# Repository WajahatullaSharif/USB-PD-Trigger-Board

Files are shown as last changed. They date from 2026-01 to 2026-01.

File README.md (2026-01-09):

# **USB C PD Trigger Board**
- The USB PD Trigger Board is based on **AP33771C USB PD3.1 ERP sink controller** from Diodes Incorporated. 
- This board negotiates required **voltages (5V/9V/12V/15V/20V/28V) and current (0 to 5A max)** profiles requested using the respective jumpers with the Type C Power Source (typically charger/adaptor). 
- It includes safety features like Over/Under Voltage, Over Current, Over Temperature Protections along with IN/OUT isolation. The board is also immune to ± 30 kV Air/Contact ESD dicharge (IEC 61000-4-2)

# Kicad 9 files
- The hardware is designed on KiCad 9.
## Schematic
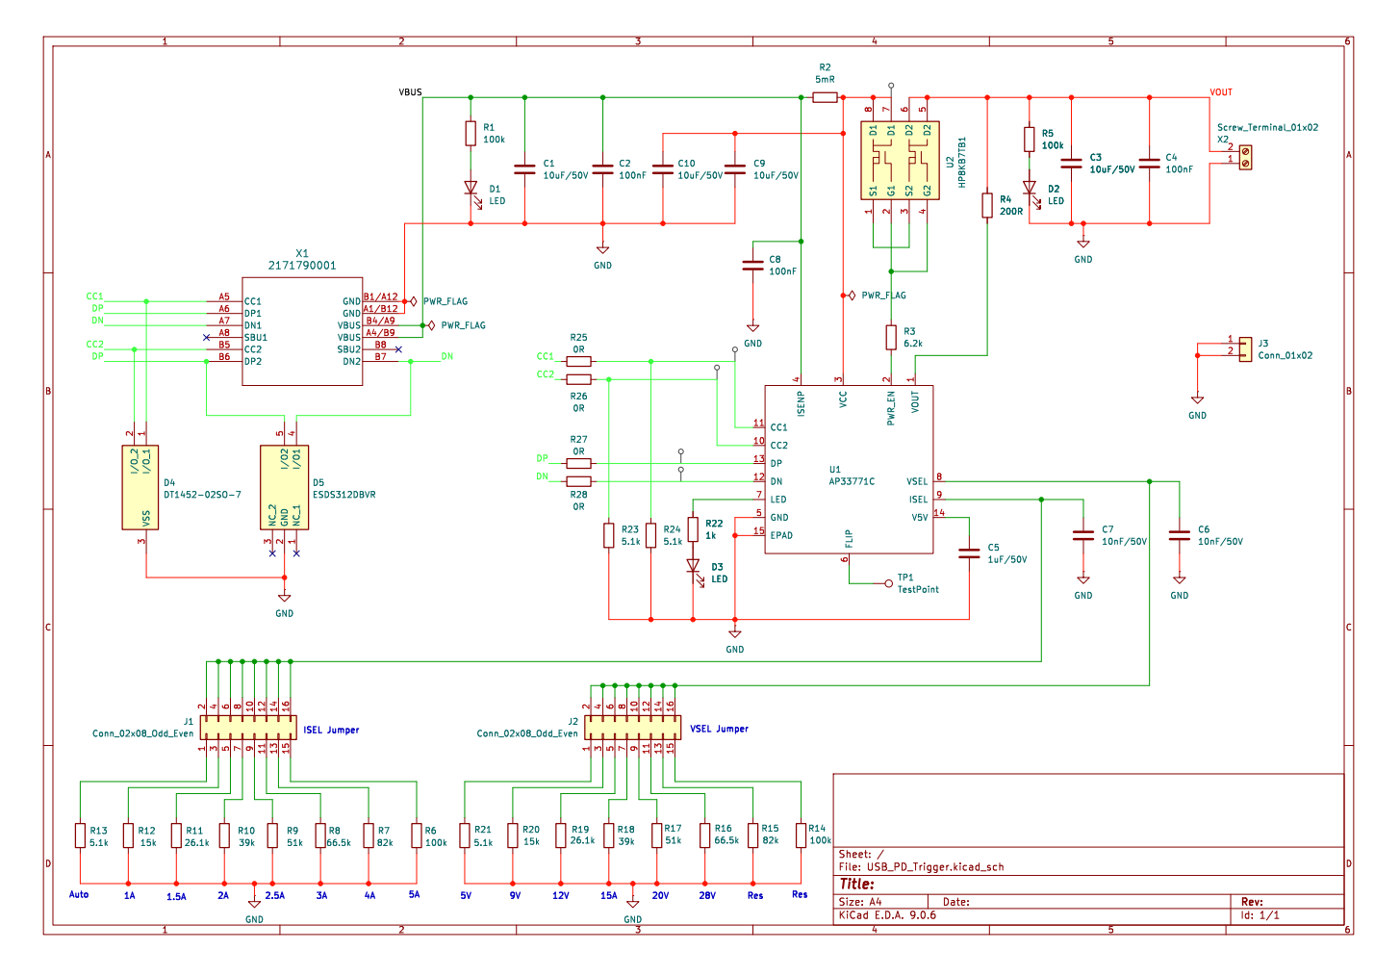
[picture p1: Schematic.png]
Schematic

## Layout
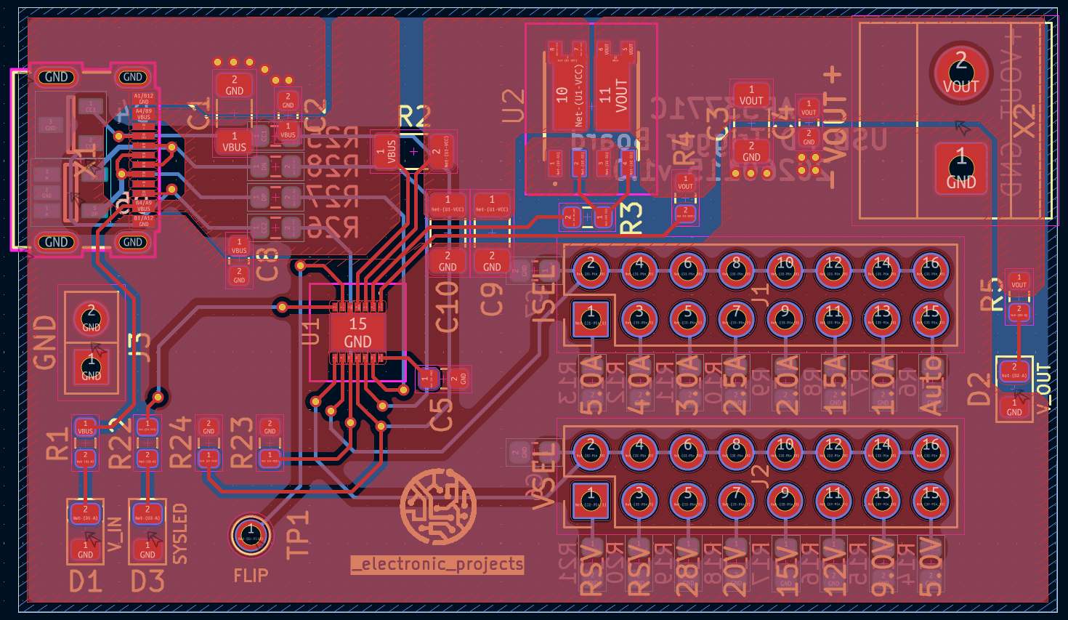
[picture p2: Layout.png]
Layout

## 3D Model
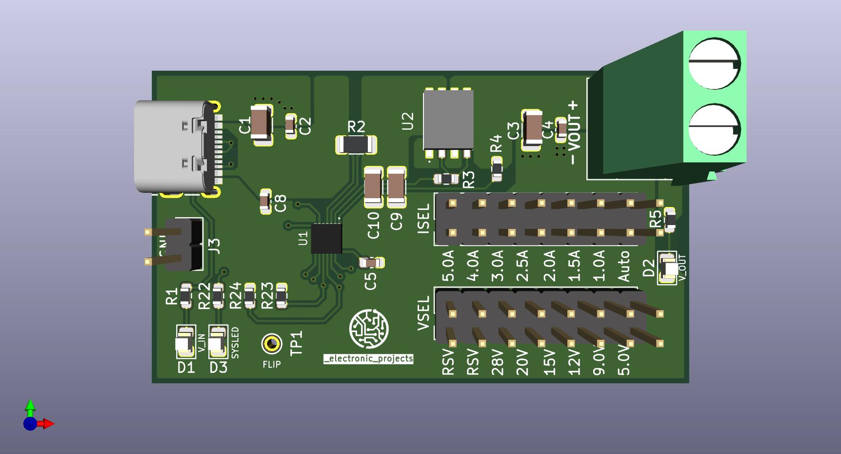
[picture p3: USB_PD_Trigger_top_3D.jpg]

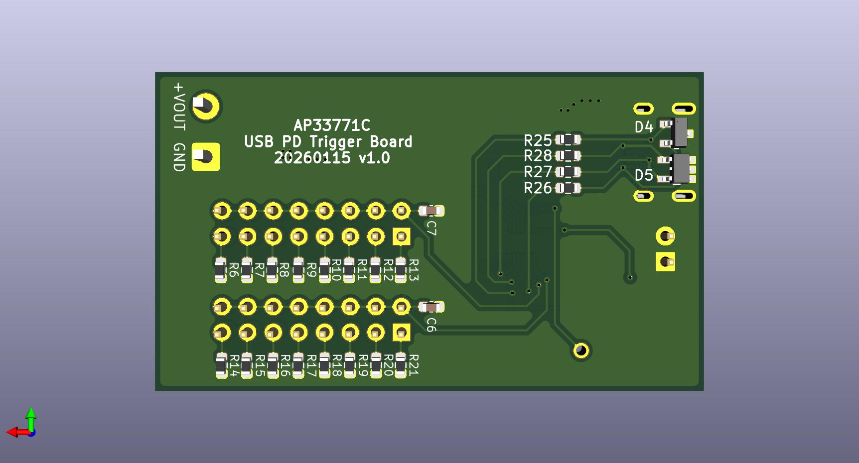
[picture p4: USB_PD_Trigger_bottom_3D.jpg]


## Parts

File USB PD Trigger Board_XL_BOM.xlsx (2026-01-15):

Sr.No | Ref Des | Qty | Value | MPN | Make | Alternates/Substitutes | Make | Total Cost
1 | C1, C3, C9, C10 | 4 | CER 10UF 50V X7R 1206 | CL31B106KBHNNNE | Samsung Electro-Mechanics |  |  | ₹167.00
2 | C2, C4, C8 | 3 | CER 100nF ±10% 50V X7R 0603 | GRM188R71H104KA93D | Murata |  |  | ₹92.00
3 | C5 | 1 | CER 1uF ±10% 50V X7R 0603 | CC0603KRX7R9BB105 | YAGEO |  |  | ₹163.00
4 | C6, C7 | 2 | CER 10nF ±10% 50V X7R 0603 | CC0603KRX7R9BB103 | YAGEO |  |  | ₹25.00
5 | D1 | 1 | 0805 GREEN SMD LED | APT2012CGCK | Kingbright |  |  | ₹149.00
6 | D2 | 1 | 0805 BLUE SMD LED | APT2012LVBC/D | Kingbright |  |  | ₹282.00
7 | D3 | 1 | 0805 ORANGE SMD LED | APT2012SECK/J4-PRV | Kingbright |  |  | ₹271.00
8 | D4 | 1 | TVS DIODE 5.5VWM 11VC SOT233 | DT1452-02SO-7 | Diodes Incorporated |  |  | ₹223.00
9 | D5 | 1 | TVS DIODE 3.6VWM 6.5VC SOT23-5 | ESDS312DBVR | Texas Instruments |  |  | ₹321.00
10 | U1 | 1 | USB EXT POWER RANGE W-DFN3030-14 | AP33771CFBZ-13-FA01 | Diodes Incorporated |  |  | ₹834.00
11 | U2 | 1 | 40V 24A, Dual Nch+Nch, HSOP8 | HP8KB7TB1 | ROHM Semiconductor |  |  | ₹1850.00
12 | R1, R5, R6, R14 | 4 | RES 100K OHM 1% 1/10W 0603 | RC0603FR-07100KL | YAGEO |  |  | ₹14.00
13 | R2 | 1 | RES 5m OHM 1% 1/2W 1206 | PA1206FRF7W0R005L | YAGEO |  |  | ₹300.00
14 | R3 | 1 | RES 6.2K OHM 5% 1/10W 0603 | RC0603JR-076K2L | YAGEO |  |  | ₹79.00
15 | R4 | 1 | RES 200Ohms 1/10W 0603 5 % | AF0603JR-07200RL | YAGEO |  |  | ₹79.00
16 | R7, R15 | 2 | RES 82K OHM 1% 1/10W 0603 | RC0603FR-0782KL | YAGEO |  |  | ₹15.00
17 | R8, R16 | 2 | RES 66.5K OHM 1% 1/10W 0603 | RC0603FR-0766K5L | YAGEO |  |  | ₹15.00
18 | R9, R17 | 2 | RES 52.3K OHM 1% 1/10W 0603 | RC0603FR-0752K3L | YAGEO |  |  | ₹27.00
19 | R10, R18 | 2 | RES 39K OHM 1% 1/10W 0603 | RC0603FR-0739KL | YAGEO |  |  | ₹15.00
20 | R11, R19 | 2 | RES 26.1K OHM 1% 1/10W 0603 | RC0603FR-0726K1L | YAGEO |  |  | ₹17.00
21 | R12, R20 | 2 | RES 15K OHM 1% 1/10W 0603 | RC0603FR-0715KL | YAGEO |  |  | ₹17.00
22 | R13, R21, R23, R24 | 4 | RES 5.1K OHM 1% 1/10W 0603 | RC0603FR-075K1L | YAGEO |  |  | ₹26.00
23 | R22 | 1 | RES 1K OHM 5% 1/10W 0603 | RC0603JR-071KL | YAGEO |  |  | ₹61.00
24 | R25, R26, R27, R28 | 4 | RES 0 OHM JUMPER 1/10W 0603 | RC0603JR-070RL | YAGEO |  |  | ₹26.00
25 | J1, J2 | 2 | Pin Header 16 Position 2.54mm Pitch Dual Row Through Hole -40℃~+105℃ | PZ254V-12-16P | XFCN | 5-146254-4 | TE Connectivity
26 | J3 | 1 | CONN HEADER VERT 2POS 2.54MM | TSW-102-07-F-S | Samtec Inc.
27 | X1 | 1 | CONN RCP USB2.0 TYP C 24P SMD RA | 2171790001 | Molex |  |  | ₹520.00
28 | X2 | 1 | 2 Position Wire to Board Terminal Block Through Hole 5mm | KF301-5.0-2P | Cixi Kefa Elec | TB002-500-02BE | Same Sky
 |  |  |  |  |  | TSW-108-07-F-D | Samtec Inc.
 |  |  |  |  |  | 691137710002 | Würth Elektronik
 |  |  |  |  |  |  | Shipping cost | ₹250.00
 |  |  |  |  |  |  | Total cost | ₹5838.00

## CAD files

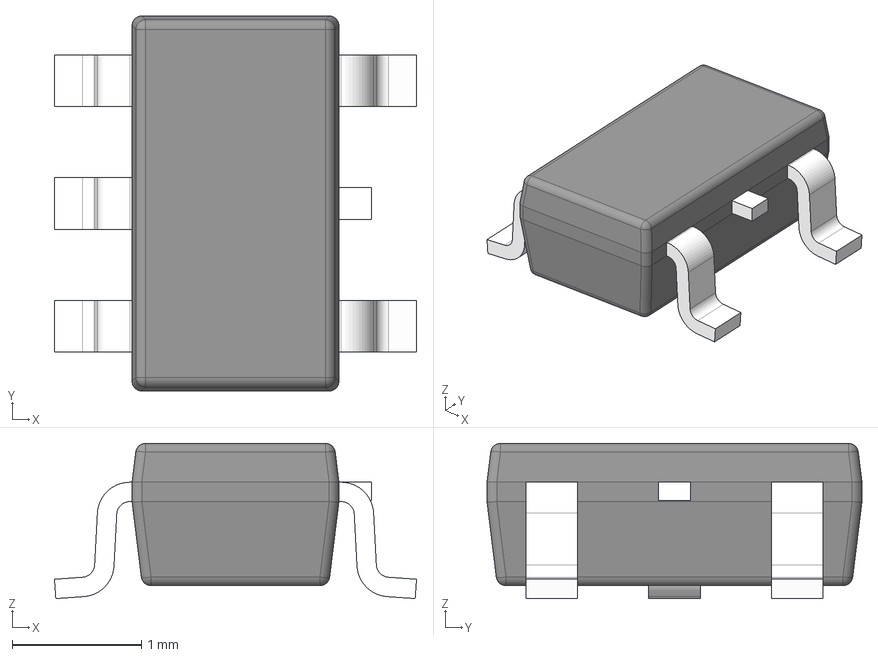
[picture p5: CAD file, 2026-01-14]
3dmodels/ESDS312DBVR.stp
2.80 x 2.90 x 1.20 mm
BODY-SOT
LEAD-SOT x 5
LEAD-DUMMY

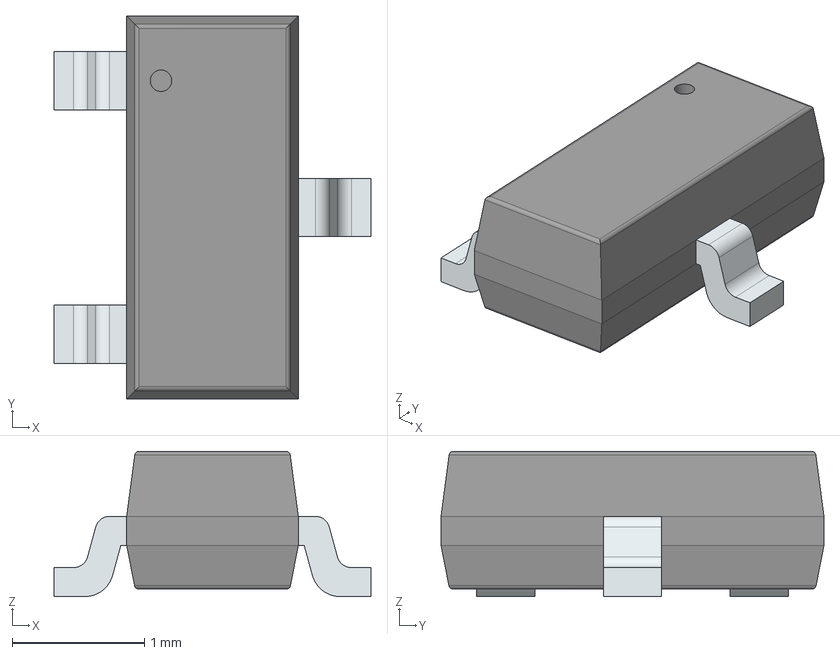
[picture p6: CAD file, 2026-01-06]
3dmodels/DT1452-02SO-7.stp
2.40 x 2.90 x 1.10 mm
PinsArrayL
FilletPinR

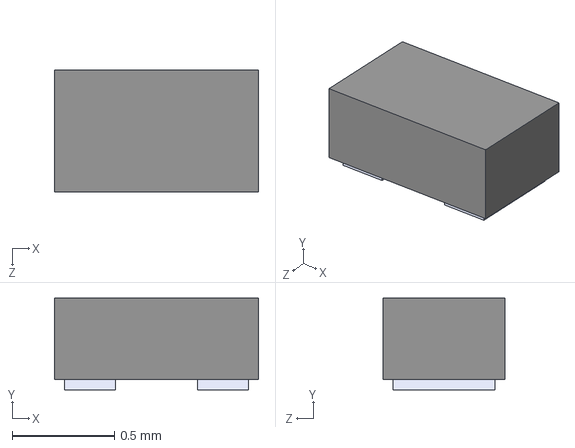
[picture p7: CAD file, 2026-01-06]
3dmodels/ESD321DPYR.STEP
1.00 x 0.45 x 0.6 mm

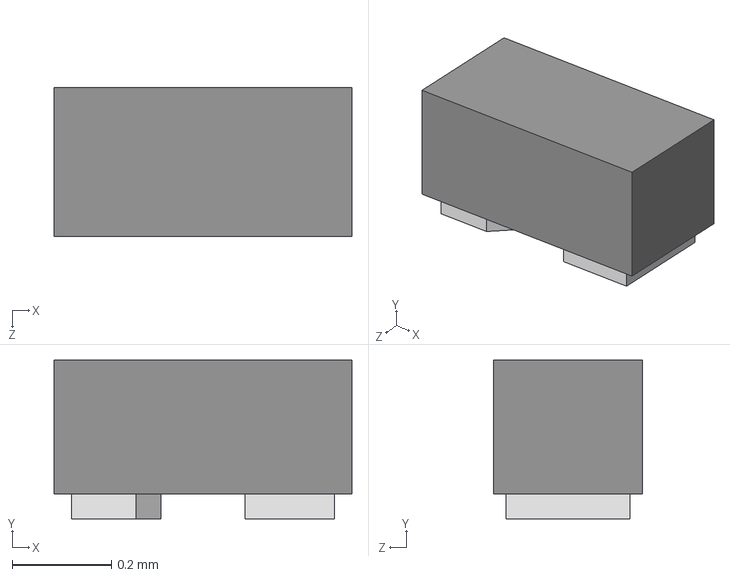
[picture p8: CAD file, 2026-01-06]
3dmodels/ESD441DPLR.stp
0.6 x 0.32 x 0.3 mm

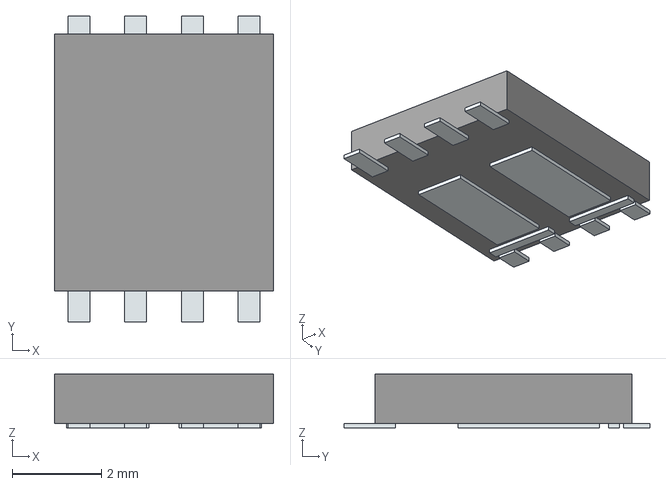
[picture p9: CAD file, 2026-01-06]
3dmodels/HP8KB7TB1.stp
4.90 x 6.84 x 1.20 mm
Pins

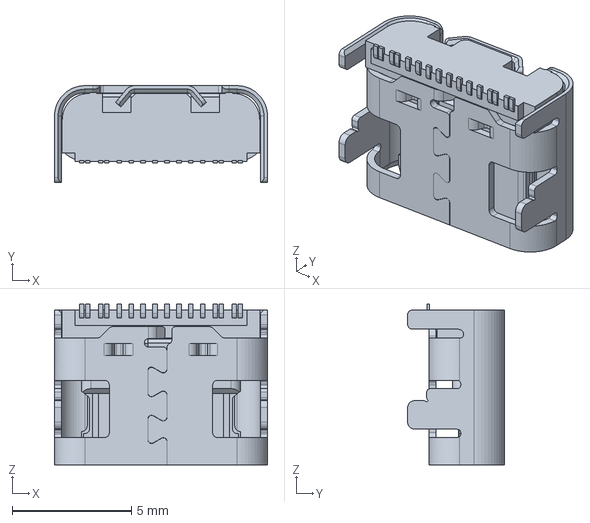
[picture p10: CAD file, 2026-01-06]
3dmodels/2171790001.stp
8.94 x 4.06 x 6.75 mm

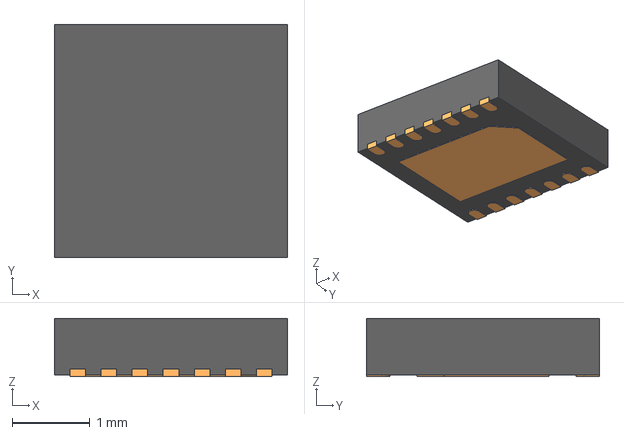
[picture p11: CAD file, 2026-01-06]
3dmodels/AP33771CFBZ-13-FA01.stp
3.00 x 3.00 x 0.75 mm

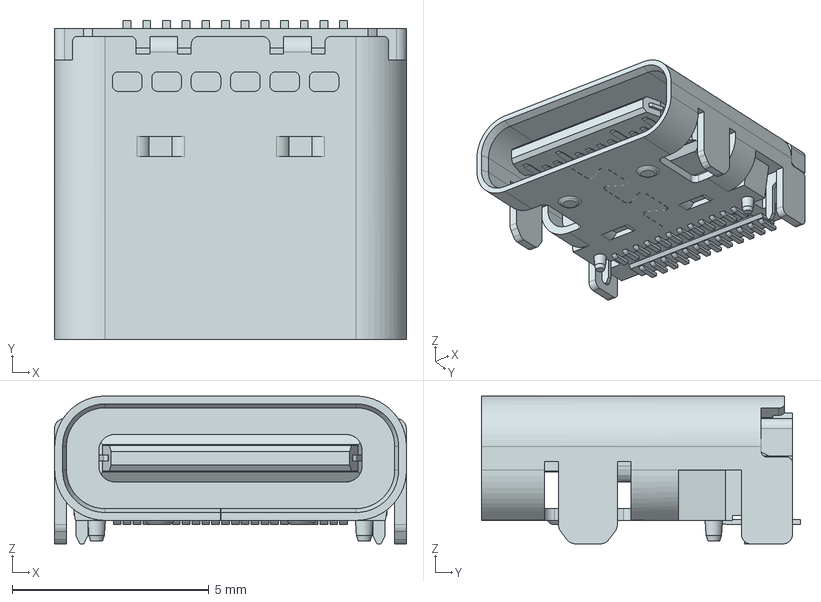
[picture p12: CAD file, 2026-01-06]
3dmodels/2216100001.stp
8.94 x 8.10 x 3.76 mm

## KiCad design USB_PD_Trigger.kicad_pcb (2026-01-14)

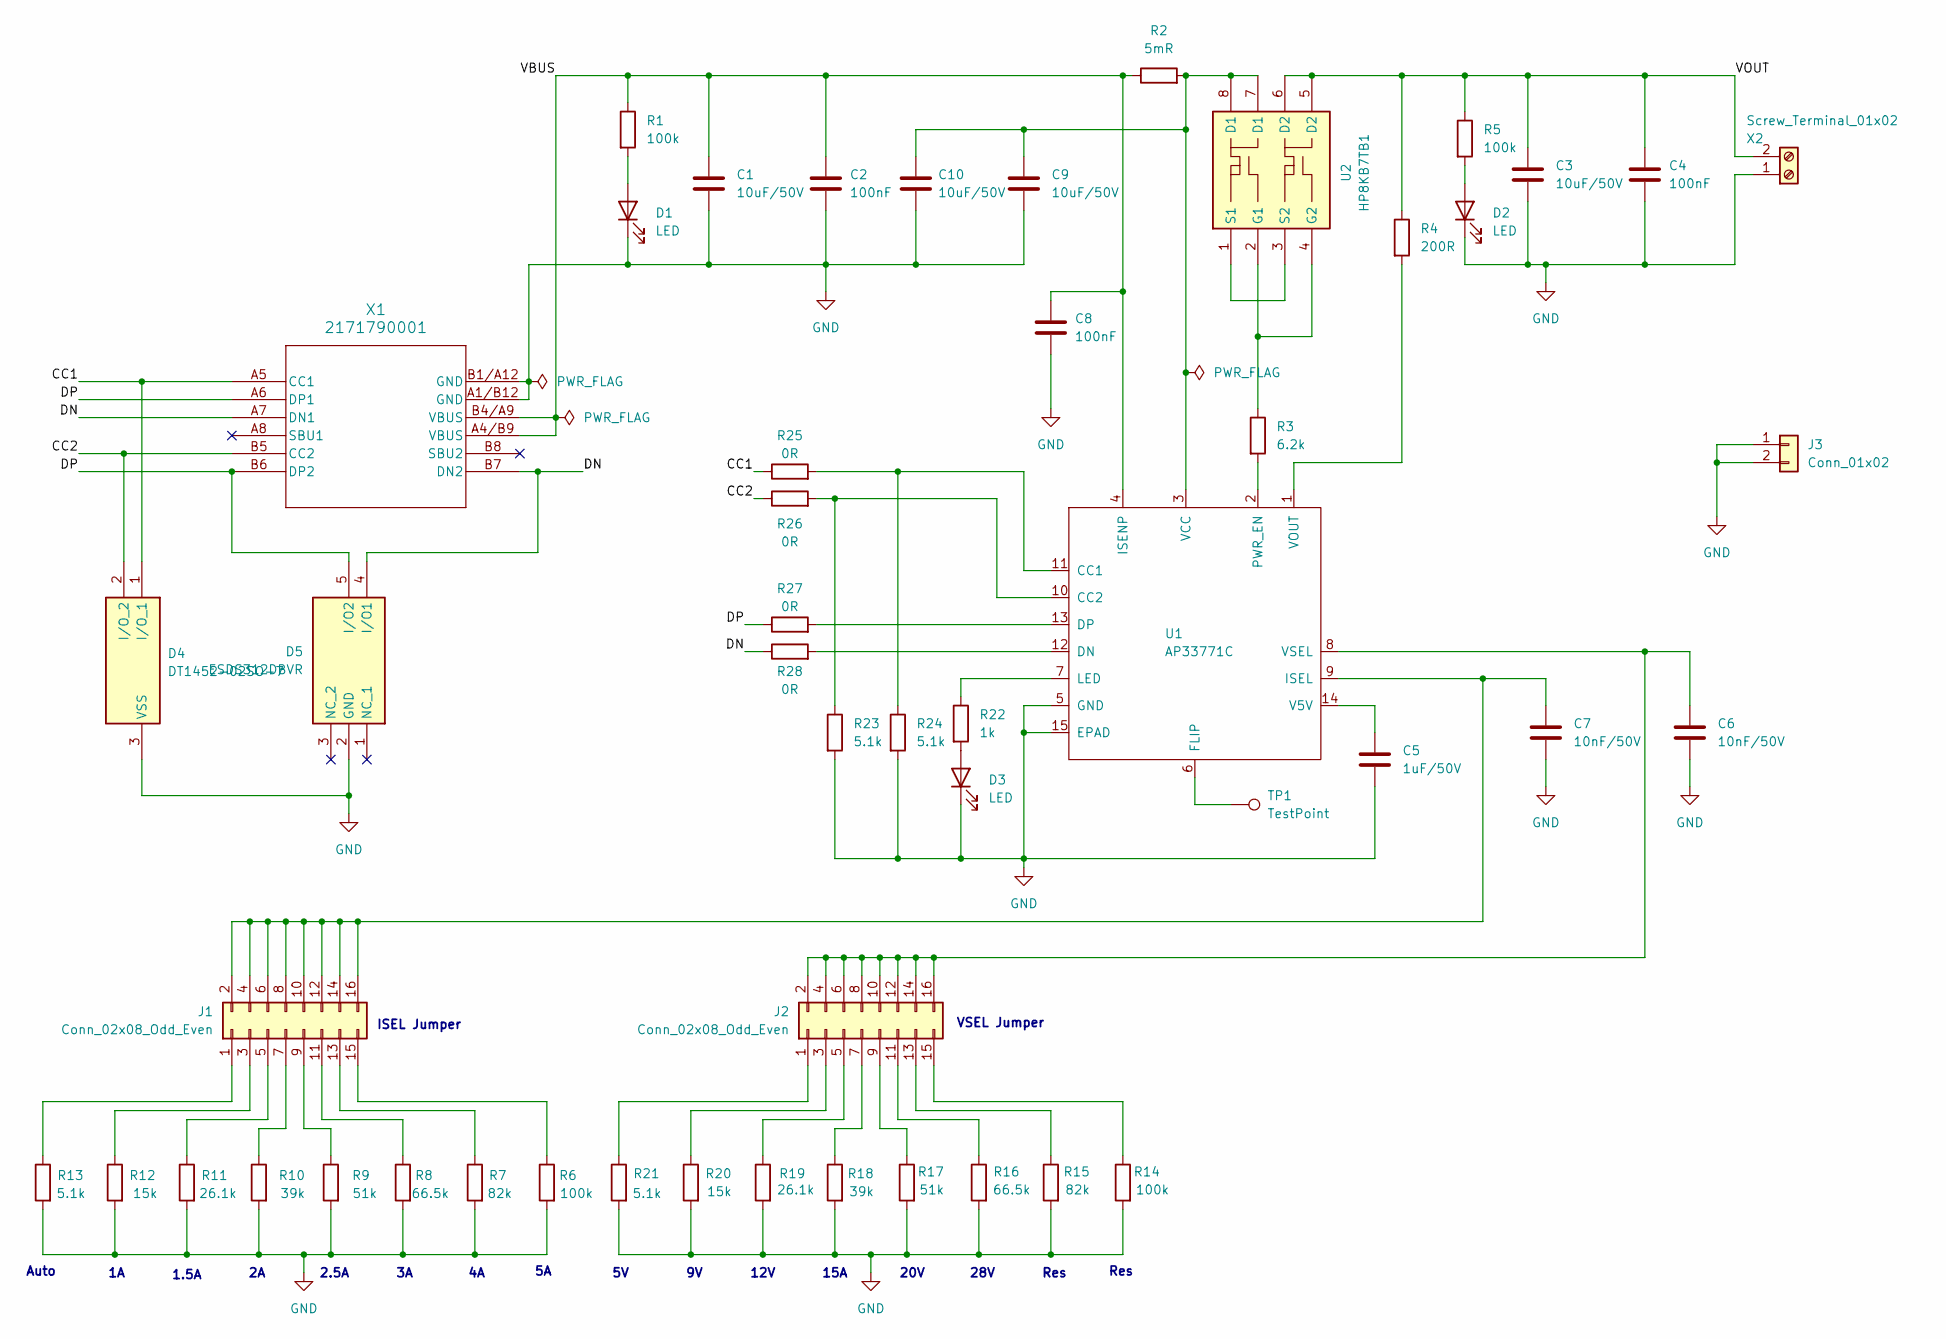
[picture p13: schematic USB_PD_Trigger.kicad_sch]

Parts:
C1, C3, C9, C10: 10uF/50V; C_1206_3216Metric; Manufacturer_Part_Number CL31B106KBHNNNE
C2, C4, C8: 100nF; C_0603_1608Metric; Manufacturer_Part_Number GRM188R71H104KA93D
C5: 1uF/50V; C_0603_1608Metric; Manufacturer_Part_Number CC0603KRX7R9BB105
C6, C7: 10nF/50V; C_0603_1608Metric; Manufacturer_Part_Number CC0603KRX7R9BB103
D1, D2, D3: LED; LED_0805_2012Metric
D4: DT1452-02SO-7; Mouser Part Number 621-DT1452-02SO-7
D5: ESDS312DBVR; Mouser Part Number 595-ESDS312DBVR
J1, J2: Conn_02x08_Odd_Even; PinHeader_2x08_P2.54mm_Vertical
J3: Conn_01x02; PinHeader_1x02_P2.54mm_Vertical
R1, R5, R6, R14: 100k; R_0603_1608Metric
R2: 5mR; R_1206_3216Metric
R3: 6.2k; R_0603_1608Metric
R4: 200R; R_0603_1608Metric
R7, R15: 82k; R_0603_1608Metric
R8, R16: 66.5k; R_0603_1608Metric
R9, R17: 51k; R_0603_1608Metric
R10, R18: 39k; R_0603_1608Metric
R11, R19: 26.1k; R_0603_1608Metric
R12, R20: 15k; R_0603_1608Metric
R13, R21, R23, R24: 5.1k; R_0603_1608Metric
R22: 1k; R_0603_1608Metric
R25, R26, R27, R28: 0R; R_0603_1608Metric
TP1: TestPoint; TestPoint_Keystone_5000-5004_Miniature
U1: AP33771C; AP33771CFBZ13FA01
U2: HP8KB7TB1; Manufacturer_Part_Number HP8KB7TB1
X1: 2171790001; 2171790001_MOL
X2: Screw_Terminal_01x02; TerminalBlock_Phoenix_MKDS-1,5-2_1x02_P5.00mm_Horizontal

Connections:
/CC1: D4.1 (I/O_1), R25.1, X1.A5 (CC1)
/CC2: D4.2 (I/O_2), R26.1, X1.B5 (CC2)
/DN: D5.4 (I/O1), R28.1, X1.A7 (DN1), X1.B7 (DN2)
/DP: D5.5 (I/O2), R27.1, X1.A6 (DP1), X1.B6 (DP2)
/VBUS: C1.1, C2.1, C8.1, R1.1, R2.1, U1.4 (ISENP), X1.A4/B9 (VBUS), X1.B4/A9 (VBUS)
/VOUT: C3.1, C4.1, R4.1, R5.1, U2.5 (D2), U2.6 (D2), U2.11, U2.12, X2.2
GND: C1.2, C2.2, C3.2, C4.2, C5.2, C6.2, C7.2, C8.2, C9.2, C10.2, D1.1 (K), D2.1 (K), D3.1 (K), D4.3 (VSS), D5.1 (NC_1), D5.2 (GND), D5.3 (NC_2), J3.1, J3.2, R6.2, R7.2, R8.2, R9.2, R10.2, R11.2, R12.2, R13.2, R14.2, R15.2, R16.2, R17.2, R18.2, R19.2, R20.2, R21.2, R23.2, R24.2, U1.5 (GND), U1.15 (EPAD), X1.A1/B12 (GND), X1.B1/A12 (GND), X2.1
unnamed: D1.2 (A), R1.2
unnamed: D2.2 (A), R5.2
unnamed: D3.2 (A), R22.2
unnamed: J1.1, R13.1
unnamed: J1.3, R12.1
unnamed: J1.5, R11.1
unnamed: J1.7, R10.1
unnamed: J1.9, R9.1
unnamed: C7.1, J1.2, J1.4, J1.6, J1.8, J1.10, J1.12, J1.14, J1.16, U1.9 (ISEL)
unnamed: J1.11, R8.1
unnamed: J1.13, R7.1
unnamed: J1.15, R6.1
unnamed: J2.1, R21.1
unnamed: J2.3, R20.1
unnamed: J2.5, R19.1
unnamed: J2.7, R18.1
unnamed: J2.9, R17.1
unnamed: C6.1, J2.2, J2.4, J2.6, J2.8, J2.10, J2.12, J2.14, J2.16, U1.8 (VSEL)
unnamed: J2.11, R16.1
unnamed: J2.13, R15.1
unnamed: J2.15, R14.1
unnamed: R24.1, R25.2, U1.11 (CC1)
unnamed: R23.1, R26.2, U1.10 (CC2)
unnamed: R28.2, U1.12 (DN)
unnamed: R27.2, U1.13 (DP)
unnamed: TP1.1, U1.6 (FLIP)
unnamed: R22.1, U1.7 (LED)
unnamed: R3.2, U1.2 (PWR_EN)
unnamed: C5.1, U1.14 (V5V)
unnamed: C9.1, C10.1, R2.2, U1.3 (VCC), U2.7 (D1), U2.8 (D1), U2.9, U2.10
unnamed: R4.2, U1.1 (VOUT)
unnamed: R3.1, U2.2 (G1), U2.4 (G2)
unnamed: U2.1 (S1), U2.3 (S2)

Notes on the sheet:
20V
28V
12V
15A
1.5A
ISEL Jumper
Auto
2.5A
Res
VSEL Jumper

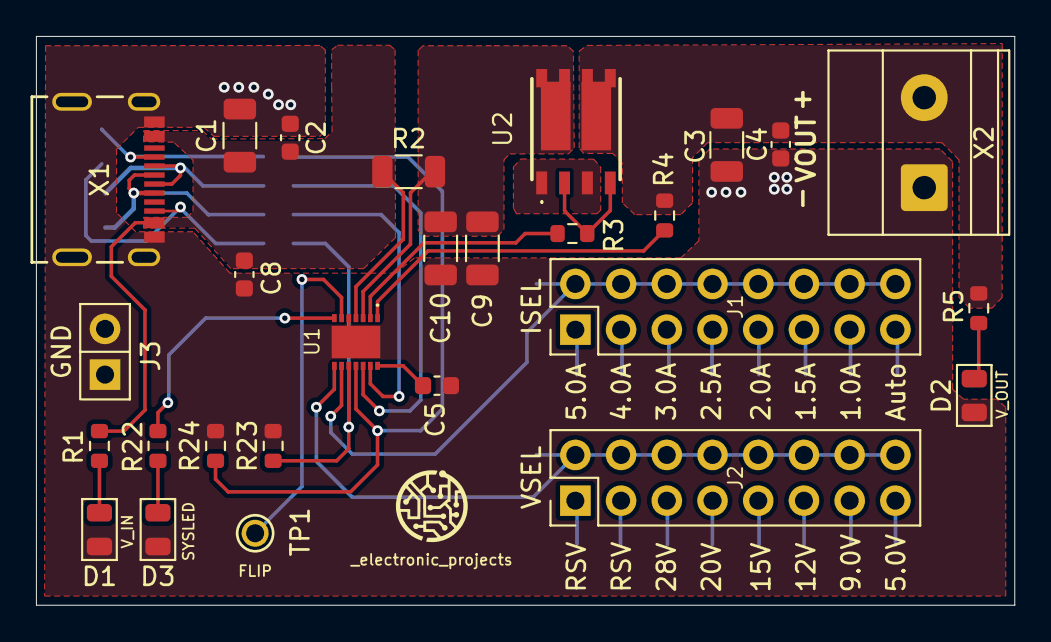
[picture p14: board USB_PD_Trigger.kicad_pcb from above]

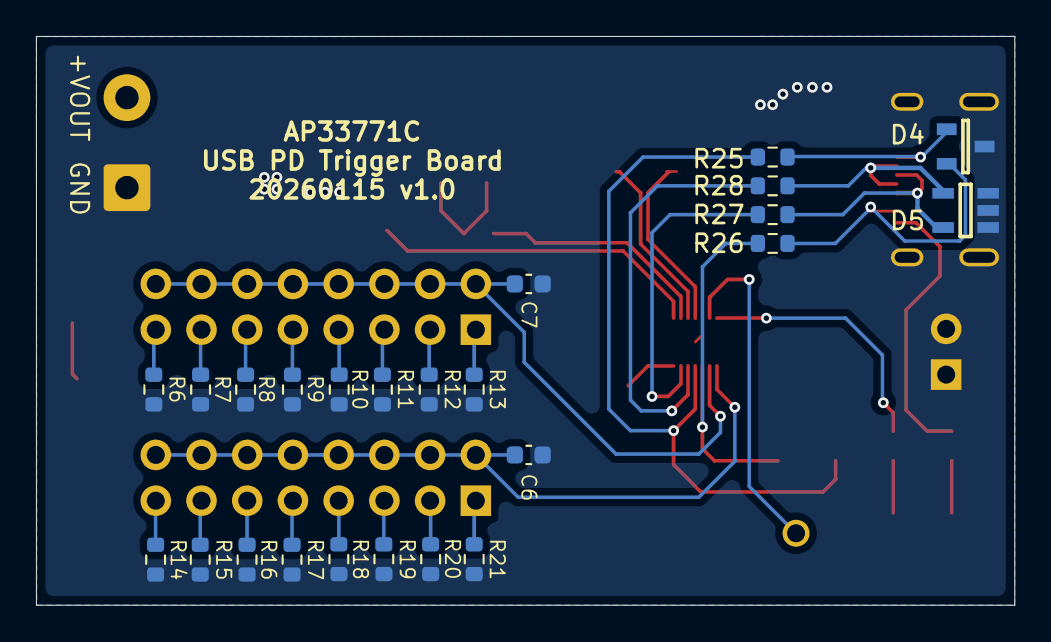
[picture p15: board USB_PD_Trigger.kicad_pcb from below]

Board: 2 copper layers, 54.4 x 31.6 mm, 51 parts (24 on the bottom side), 40 nets.

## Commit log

2026-01-06 Add KiCad project files
    [2171790001.stp, 2216100001.stp, AP33771CFBZ-13-FA01.stp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]
2026-01-06 ISEL1 in Layout
    [USB_PD_Trigger.kicad_pcb]
2026-01-06 ISEL in Layout
    [USB_PD_Trigger.kicad_pcb]
2026-01-07 Zones completed
    [USB_PD_Trigger.kicad_pcb]
2026-01-07 DRC errors resolution
    [USB_PD_Trigger.kicad_pcb]
2026-01-08 DRC check complete + gerbers
    [USB_PD_Trigger-B_Cu.gbl, USB_PD_Trigger-B_Mask.gbs, USB_PD_Trigger-B_Paste.gbp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]
2026-01-08 Saved PCB Layout
    [USB_PD_Trigger.kicad_pcb]
2026-01-08 Gerber pdf generation
    [USB_PD_Trigger.kicad_pcb]
2026-01-14 added stitching vias and changed ESD diodes
    [ESDS312DBVR.stp, USB_PD_Trigger.kicad_pcb, USB_PD_Trigger.kicad_sch]
2026-01-15 updated schematic and gerbers
    [USB_PD_Trigger.kicad_sch]
2026-01-15 updated BOM with cost
    [USB PD Trigger Board_XL_BOM.xlsx, USB_PD_Trigger.csv]
